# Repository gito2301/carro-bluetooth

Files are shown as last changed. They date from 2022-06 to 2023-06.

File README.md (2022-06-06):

# carro-bluetooth V0.1

# Lista de materiales
* Arduino UNO
* 1 x L293D (Puente H)
* 2 x Motores con rueda
* 1 x Resistencia 1K
* 1 x Resistencia 2.2K
* Módulo bluetooth HC-05
* Portabatería de 4 puestos
* 4 baterías alcalinas (de 1.5v, otras no serán suficiente para dar potencia a los motores)
* Base para ensamblar el carro

# Circuito

circuito

# Programación Arduino

El código para programar nuestro arduino está al interior de la carpeta arduino

# APP Android

Al interior de la carpeta android, se encuentra un proyecto simple con la aplicación de android para enviar al motor instrucciones simples de ir hacia adelante, atrás, izquierda, derecha y detenerse.

Para instalar el apk que allí reside, debe habilitarse el modo desarrollador (proceso que depende de cada celular).

# Referencias

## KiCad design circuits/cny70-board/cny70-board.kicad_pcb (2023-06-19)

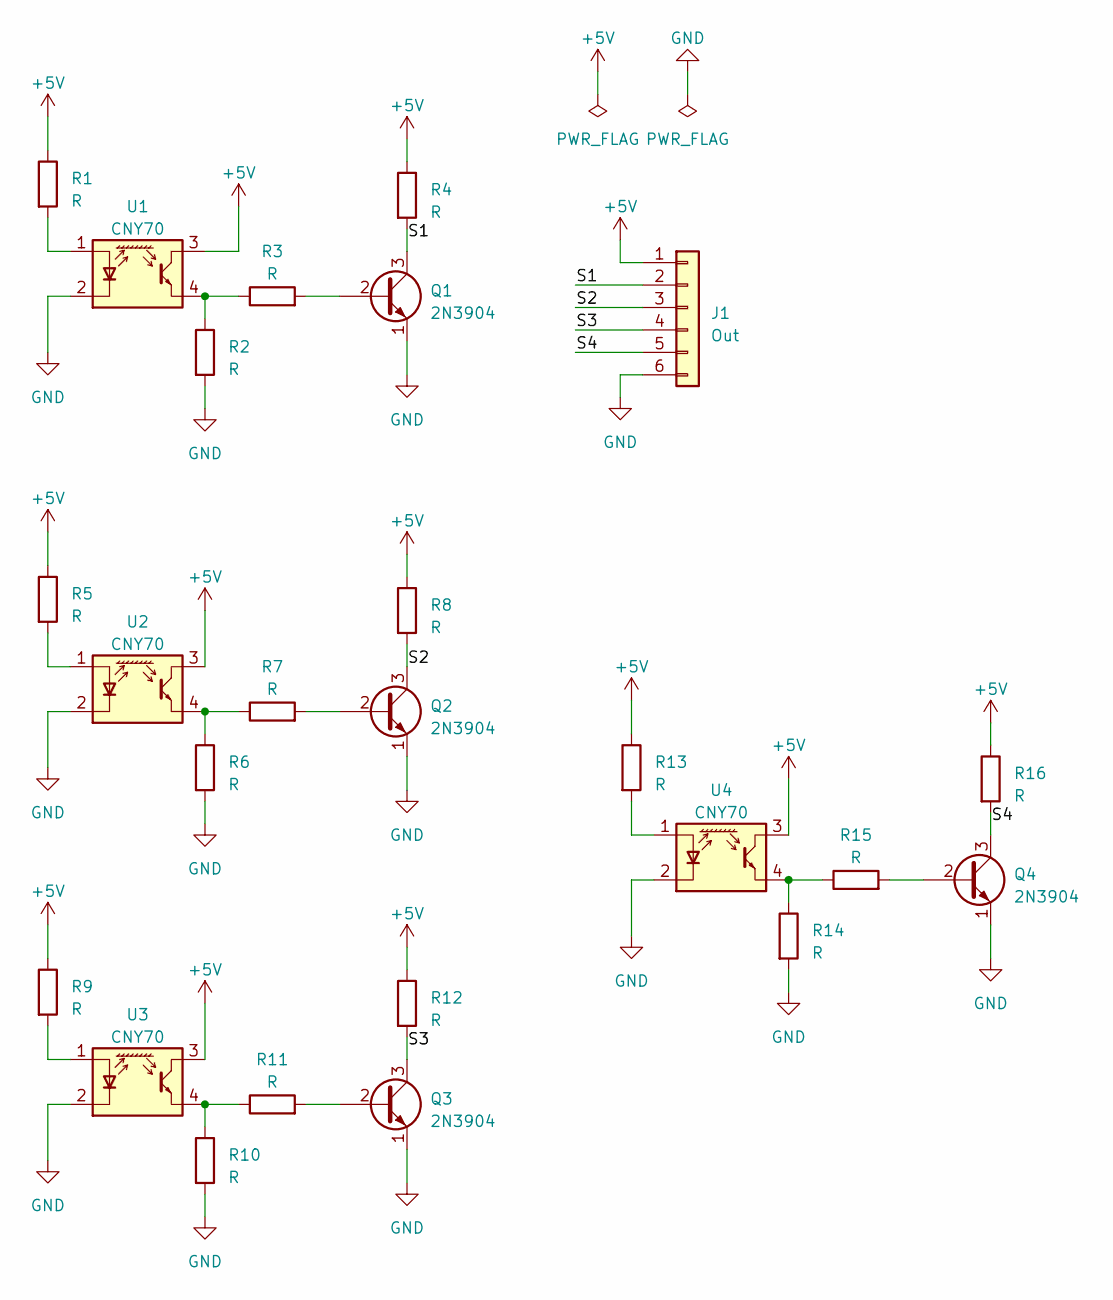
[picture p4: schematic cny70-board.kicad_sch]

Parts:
J1: Out; PinHeader_1x06_P2.00mm_Vertical
Q1, Q2, Q3, Q4: 2N3904; TO-92_Inline_Wide
R1, R2, R3, R4, R5, R6, R7, R8, R9, R10, R11, R12, R13, R14, R15, R16: R; R_Axial_DIN0207_L6.3mm_D2.5mm_P7.62mm_Horizontal
U1, U2, U3, U4: CNY70; Vishay_CNY70

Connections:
+5V: J1.1, R1.1, R4.1, R5.1, R8.1, R9.1, R12.1, R13.1, R16.1, U1.3 (C), U2.3 (C), U3.3 (C), U4.3 (C)
/S1: J1.2, Q1.3 (C), R4.2
/S2: J1.3, Q2.3 (C), R8.2
/S3: J1.4, Q3.3 (C), R12.2
/S4: J1.5, Q4.3 (C), R16.2
GND: J1.6, Q1.1 (E), Q2.1 (E), Q3.1 (E), Q4.1 (E), R2.2, R6.2, R10.2, R14.2, U1.2 (K), U2.2 (K), U3.2 (K), U4.2 (K)
unnamed: Q1.2 (B), R3.2
unnamed: Q2.2 (B), R7.2
unnamed: Q3.2 (B), R11.2
unnamed: Q4.2 (B), R15.2
unnamed: R1.2, U1.1 (A)
unnamed: R2.1, R3.1, U1.4 (E)
unnamed: R5.2, U2.1 (A)
unnamed: R6.1, R7.1, U2.4 (E)
unnamed: R9.2, U3.1 (A)
unnamed: R10.1, R11.1, U3.4 (E)
unnamed: R13.2, U4.1 (A)
unnamed: R14.1, R15.1, U4.4 (E)

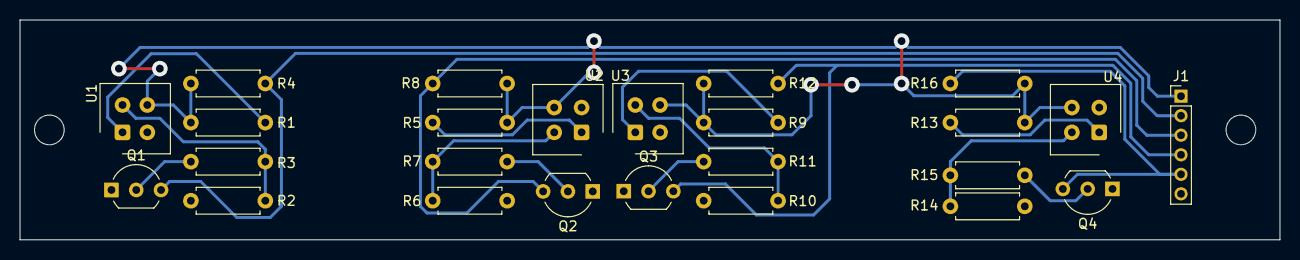
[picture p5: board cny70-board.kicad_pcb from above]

Board: 2 copper layers, 129.0 x 22.5 mm, 25 parts (0 on the bottom side), 18 nets.

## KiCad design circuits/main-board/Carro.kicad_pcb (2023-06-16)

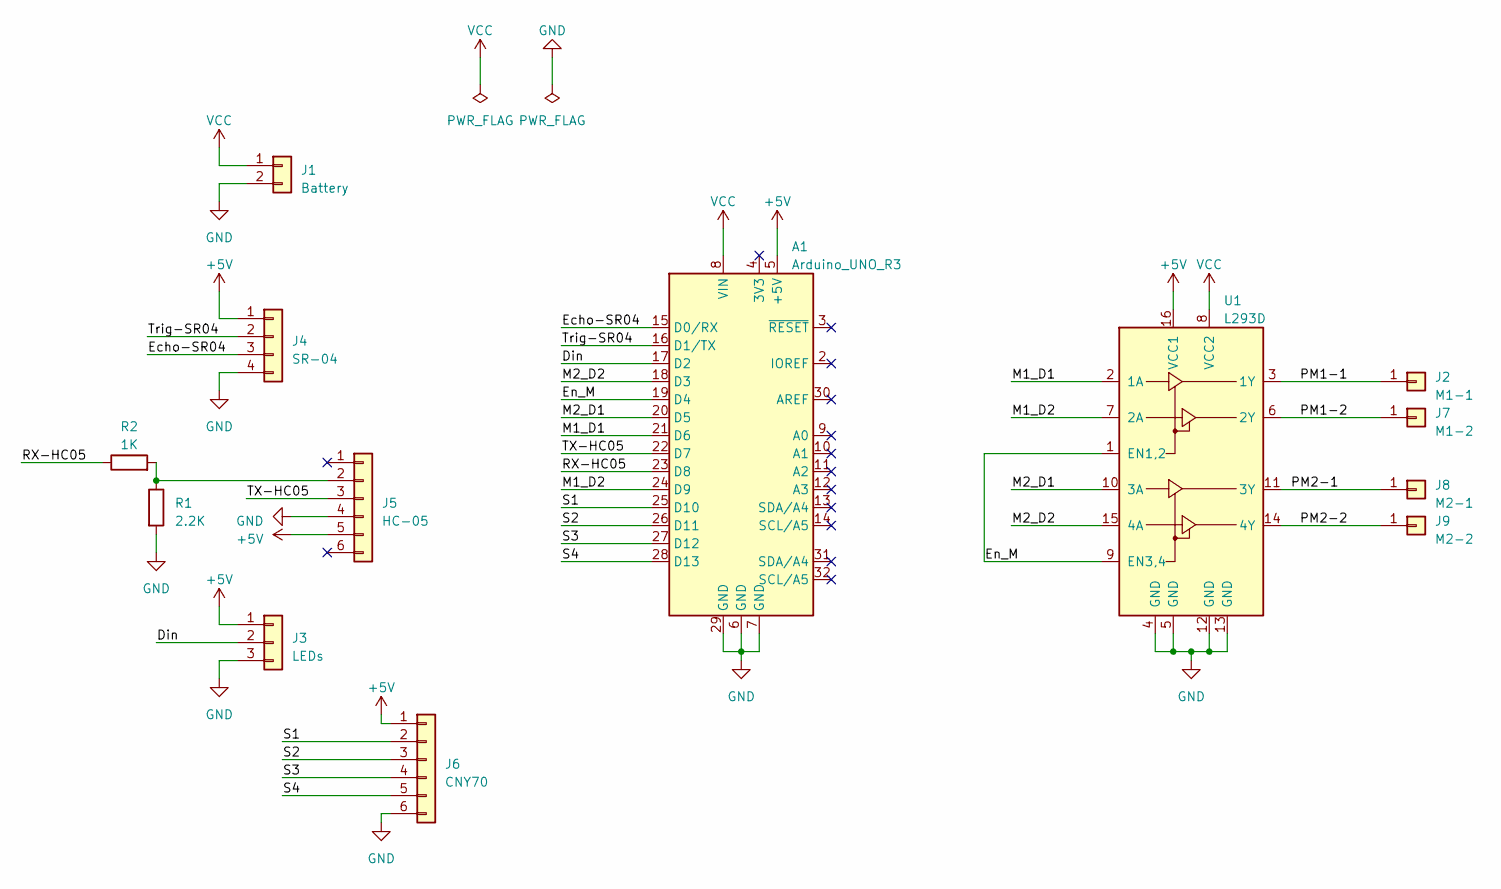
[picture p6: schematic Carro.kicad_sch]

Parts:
A1: Arduino_UNO_R3; Arduino_UNO_R3-pins
J1: Battery; PinHeader_1x02_P2.54mm_Vertical
J2: M1-1; PinHeader_1x01_P1.00mm_Horizontal
J3: LEDs; PinHeader_1x03_P2.54mm_Vertical
J4: SR-04; PinSocket_1x04_P2.54mm_Vertical
J5: HC-05; PinSocket_1x06_P2.54mm_Vertical
J6: CNY70; PinHeader_1x06_P2.54mm_Vertical
J7: M1-2; PinHeader_1x01_P1.00mm_Horizontal
J8: M2-1; PinHeader_1x01_P1.00mm_Horizontal
J9: M2-2; PinHeader_1x01_P1.00mm_Horizontal
R1: 2.2K; R_Axial_DIN0207_L6.3mm_D2.5mm_P7.62mm_Horizontal
R2: 1K; R_Axial_DIN0207_L6.3mm_D2.5mm_P7.62mm_Horizontal
U1: L293D; DIP-16_W7.62mm

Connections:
+5V: A1.5 (+5V), J3.1, J4.1, J5.5, J6.1, U1.16 (VCC1)
/Din: A1.17 (D2), J3.2
/Echo-SR04: A1.15 (D0/RX), J4.3
/En_M: A1.19 (D4), U1.1 (EN1,2), U1.9 (EN3,4)
/M1_D1: A1.21 (D6), U1.2 (1A)
/M1_D2: A1.24 (D9), U1.7 (2A)
/M2_D1: A1.20 (D5), U1.10 (3A)
/M2_D2: A1.18 (D3), U1.15 (4A)
/PM1-1: J2.1, U1.3 (1Y)
/PM1-2: J7.1, U1.6 (2Y)
/PM2-1: J8.1, U1.11 (3Y)
/PM2-2: J9.1, U1.14 (4Y)
/RX-HC05: A1.23 (D8), R2.1
/S1: A1.25 (D10), J6.2
/S2: A1.26 (D11), J6.3
/S3: A1.27 (D12), J6.4
/S4: A1.28 (D13), J6.5
/TX-HC05: A1.22 (D7), J5.3
/Trig-SR04: A1.16 (D1/TX), J4.2
GND: A1.6 (GND), A1.7 (GND), A1.29 (GND), J1.2, J3.3, J4.4, J5.4, J6.6, R1.2, U1.4 (GND), U1.5 (GND), U1.12 (GND), U1.13 (GND)
unnamed: J5.2, R1.1, R2.2
VCC: A1.8 (VIN), J1.1, U1.8 (VCC2)

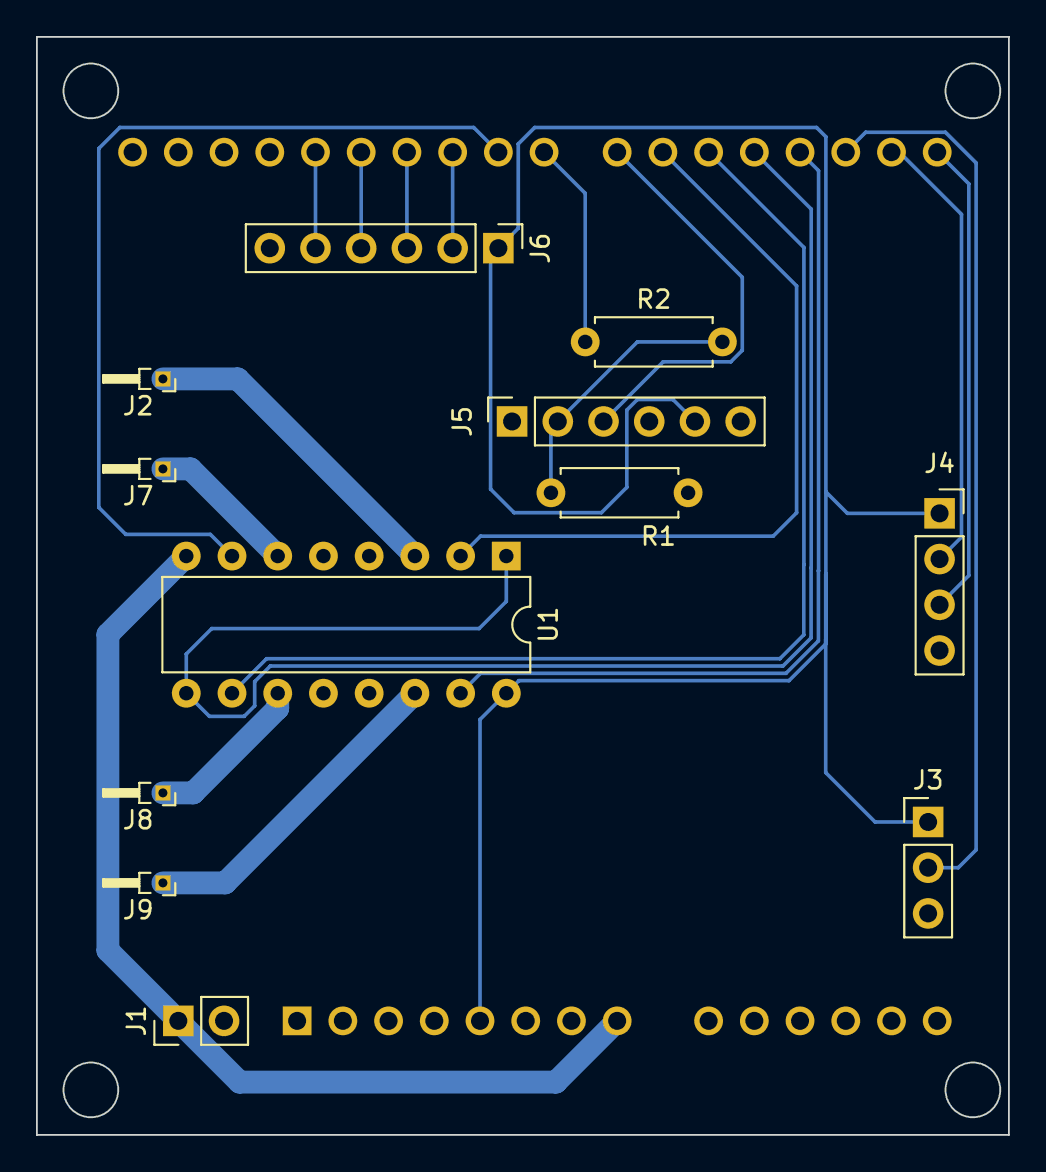
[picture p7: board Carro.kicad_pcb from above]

Board: 2 copper layers, 54.0 x 61.0 mm, 13 parts (1 on the bottom side), 22 nets.

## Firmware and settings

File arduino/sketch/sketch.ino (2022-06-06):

#include <SoftwareSerial.h>

// Bluetooth Serial
SoftwareSerial MyBlue(2,3);

// Chars to wait for in the bluetooth communication
char ADELANTE = 'u';
char ATRAS = 'd';
char PARAR = 's';
char IZQUIERDA = 'l';
char DERECHA = 'r';

// Pins for the two groups of motors (PWM pins required)
// Pin Group 1 forward
int pinG1Ad = 5;
// Pin Group 1 backward
int pinG1At = 6;
// Pin Group 2 forward
int pinG2Ad = 10;
// Pin Group 1 backward
int pinG2At = 11;

void setup() {
  // Initializa arduino serial communication
  Serial.begin(9600);
  // Initialize software serial for bluetooth
  MyBlue.begin(9600);

  Serial.println("Ready to connect\nDefault is 000 or 1234");

  // Initialize pins as output
  pinMode(pinG1Ad, OUTPUT);
  pinMode(pinG1At, OUTPUT);
  pinMode(pinG2Ad, OUTPUT);
  pinMode(pinG2At, OUTPUT);
}

void adelante(){
  Serial.println("Adelante");
  analogWrite(pinG1Ad, 0);
  analogWrite(pinG1At, 0);
  analogWrite(pinG2Ad, 0);
  analogWrite(pinG2At, 0);
  delay(500);
  analogWrite(pinG1Ad, 200);
  analogWrite(pinG2Ad, 200);
}

void parar(){
  Serial.println("Parar");
  analogWrite(pinG1Ad, 0);
  analogWrite(pinG1At, 0);
  analogWrite(pinG2Ad, 0);
  analogWrite(pinG2At, 0);
  delay(500);
}

void atras() {
  Serial.println("Atras");
  analogWrite(pinG1Ad, 0);
  analogWrite(pinG1At, 0);
  analogWrite(pinG2Ad, 0);
  analogWrite(pinG2At, 0);
  delay(500);
  analogWrite(pinG1At, 200);
  analogWrite(pinG2At, 200);
}

void izquierda(){
  Serial.println("Izquierda");
  analogWrite(pinG1Ad, 0);
  analogWrite(pinG1At, 0);
  analogWrite(pinG2Ad, 0);
  analogWrite(pinG2At, 0);
  delay(500);
  analogWrite(pinG1At, 100);
  analogWrite(pinG2Ad, 100);
}

void derecha() {
  Serial.println("Derecha");
  analogWrite(pinG1Ad, 0);
  analogWrite(pinG1At, 0);
  analogWrite(pinG2Ad, 0);
  analogWrite(pinG2At, 0);
  delay(500);
  analogWrite(pinG2At, 100);
  analogWrite(pinG1Ad, 100);
}

void loop() {
  if (MyBlue.available()){
    char data = MyBlue.read();
    if(data == ADELANTE){
      adelante();
    }else if(data == ATRAS) {
      atras();
    }else if(data == PARAR) {
      parar();
    }else if(data == IZQUIERDA) {
      izquierda();
    }else if(data == DERECHA) {
      derecha();
    }
  }
  delay(1000);
}

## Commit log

2023-05-10 First PCB Design
    Simple circuit design to use Arduino UNO with cny70, SR04, HC05, two motors with L293D and a led strip WS2812B.
    [Carro-B_Adhesive.gbr, Carro-B_Cu.gbr, Carro-B_Mask.gbr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]
2023-06-16 New CNY70 board
    Changes in tracks and spacings to match new configuration on CNC.
    [Carro-B_Adhesive.gbr, Carro-B_Cu.gbr, Carro-B_Mask.gbr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]
2023-06-19 Grb and Drl for CNY70 board - V0.1
    Grb and Drl for CNY70 board - V0.1
    [cny70-board.kicad_pcb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]
2023-06-19 Line width changed
    Path/spaces are now 0.3048/0.3048 mm (12/12 mil), and vias are 1.6-0.8 mm
    [cny70-board.kicad_pcb, cny70-board.kicad_sch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]
